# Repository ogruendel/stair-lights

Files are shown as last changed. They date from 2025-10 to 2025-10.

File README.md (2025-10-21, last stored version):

| Supported Targets | ESP32 | ESP32-C2 | ESP32-C3 | ESP32-C5 | ESP32-C6 | ESP32-C61 | ESP32-H2 | ESP32-P4 | ESP32-S2 | ESP32-S3 |
| --- | ----- | --- | --- | --- | --- | --- | --- | --- | --- | --- |

# Blink Example

(See the README.md file in the upper level 'examples' directory for more information about examples.)

This example demonstrates how to blink a LED by using the GPIO driver or using the [led_strip](https://components.espressif.com/component/espressif/led_strip) library if the LED is addressable e.g. [WS2812](https://cdn-shop.adafruit.com/datasheets/WS2812B.pdf). The `led_strip` library is installed via [component manager](main/idf_component.yml).

## How to Use Example

Before project configuration and build, be sure to set the correct chip target using `idf.py set-target <chip_name>`.

### Hardware Required

* A development board with normal LED or addressable LED on-board (e.g., ESP32-S3-DevKitC, ESP32-C6-DevKitC etc.)
* A USB cable for Power supply and programming

See [Development Boards](https://www.espressif.com/en/products/devkits) for more information about it.

### Configure the Project

Open the project configuration menu (`idf.py menuconfig`).

In the `Example Configuration` menu:

* Select the LED type in the `Blink LED type` option.
  * Use `GPIO` for regular LED
  * Use `LED strip` for addressable LED
* If the LED type is `LED strip`, select the backend peripheral
  * `RMT` is only available for ESP targets with RMT peripheral supported
  * `SPI` is available for all ESP targets
* Set the GPIO number used for the signal in the `Blink GPIO number` option.
* Set the blinking period in the `Blink period in ms` option.

### Build and Flash

Run `idf.py -p PORT flash monitor` to build, flash and monitor the project.

(To exit the serial monitor, type ``Ctrl-]``.)

See the [Getting Started Guide](https://docs.espressif.com/projects/esp-idf/en/latest/get-started/index.html) for full steps to configure and use ESP-IDF to build projects.

## Example Output

As you run the example, you will see the LED blinking, according to the previously defined period. For the addressable LED, you can also change the LED color by setting the `led_strip_set_pixel(led_strip, 0, 16, 16, 16);` (LED Strip, Pixel Number, Red, Green, Blue) with values from 0 to 255 in the [source file](main/blink_example_main.c).

```text
I (315) example: Example configured to blink addressable LED!
I (325) example: Turning the LED OFF!
I (1325) example: Turning the LED ON!
I (2325) example: Turning the LED OFF!
I (3325) example: Turning the LED ON!
I (4325) example: Turning the LED OFF!
I (5325) example: Turning the LED ON!
I (6325) example: Turning the LED OFF!
I (7325) example: Turning the LED ON!
I (8325) example: Turning the LED OFF!
```

Note: The color order could be different according to the LED model.

The pixel number indicates the pixel position in the LED strip. For a single LED, use 0.

## Troubleshooting

* If the LED isn't blinking, check the GPIO or the LED type selection in the `Example Configuration` menu.

For any technical queries, please open an [issue](https://github.com/espressif/esp-idf/issues) on GitHub. We will get back to you soon.

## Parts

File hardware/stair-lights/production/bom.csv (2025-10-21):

Designator | Footprint | Quantity | Value | LCSC Part #
 |  | 1
AE1 | 1206 | 1 | Antenna_Chip
BT1 | BatteryHolder_Keystone_1042_1x18650 | 1 | 18650 | C2988620
C1 | 0402 | 1 | 0.5pF
C10, C7 | 0603 | 2 | 1uF | C1592
C11, C12, C13, C18, C5 | 0402 | 5 | 100nF | C6119799
C14, C8, C9 | 0402 | 3 | 4.7uF | C23733
C15, C16 | 0603 | 2 | 10uF | C6119842
C17 | 0603 | 1 | 22uF | C380323
C2, C3 | 0402 | 2 | 12pF | C45359894
C4 | 0402 | 1 | 0.8pF
C6 | 0402 | 1 | 100pF | C77177
D1 | LED_1.7x1.1mm | 1 | LED_RED | C965860
D2 | LED_1.7x1.1mm | 1 | LED_GREEN | C965863
J1 | USB_C_Receptacle_GCT_USB4105-xx-A_16P_TopMnt_Horizontal | 1 | USB_C_Receptacle_USB2.0_14P | C2765186
J2 | JST_XH_S3B-XH-A_1x03_P2.50mm_Horizontal | 1 | Conn_01x03 | C157928
J3 | JST_XH_B3B-XH-AM_1x03_P2.50mm_Vertical | 1 | Conn_01x03 | C161870
J4 | JST_XH_B4B-XH-AM_1x04_P2.50mm_Vertical | 1 | Conn_01x04 | C161871
J5 | JST_XH_S15B-XH-A_1x15_P2.50mm_Horizontal | 1 | Conn_01x15
L1 | 0402 | 1 | 4.7nH
L2 | 1008 | 1 | 0.47uH | C5832368
Q1 | SOT-23 | 1 | SI2301-ZE | C5261052
Q10, Q11, Q12, Q13, Q14, Q15, Q16, Q3, Q4, Q5, Q6, Q7, Q8, Q9 | SOT-23 | 14 | 2302V | C7431443
Q2 | SOT-23-6 | 1 | FS8205A | C2830320
R1, R2 | 0603 | 2 | 5.1k | C26000
R10 | 0402 | 1 | 1M | C26083
R11 | 0603 | 1 | 100R | C2907089
R12 | 0603 | 1 | 2k | C22975
R13, R14, R15, R16, R17, R18, R19, R20, R21, R22, R23, R24, R25, R26, R3, R4, R5 | 0603 | 17 | 220R | C2907127
R6 | 0603 | 1 | 1.2k | C25987
R7 | 0402 | 1 | 511k | C5126239
R8 | 0402 | 1 | 91k | C4147
R9 | 0402 | 1 | 2M | C138014
TP1 | TestPoint_Pad_D1.5mm | 1 | #RST
TP2 | TestPoint_Pad_D1.5mm | 1 | SWDCLK
TP3 | TestPoint_Pad_D1.5mm | 1 | SWDIO
U1 | Nordic_AQFN-73-1EP_7x7mm_P0.5mm | 1 | nRF52840 | C190794
U2 | SOIC-8-1EP_3.9x4.9mm_P1.27mm_EP2.41x3.3mm_ThermalVias | 1 | TP4056-42-ESOP8 | C7473158
U3 | VSON-10 | 1 | TPS63802DLAR | C2845237
U4 | SOT-23-6 | 1 | DW01A | C18164398
Y1 | Crystal_SMD_2016-4Pin_2.0x1.6mm | 1 | Crystal_GND24 | C37635331

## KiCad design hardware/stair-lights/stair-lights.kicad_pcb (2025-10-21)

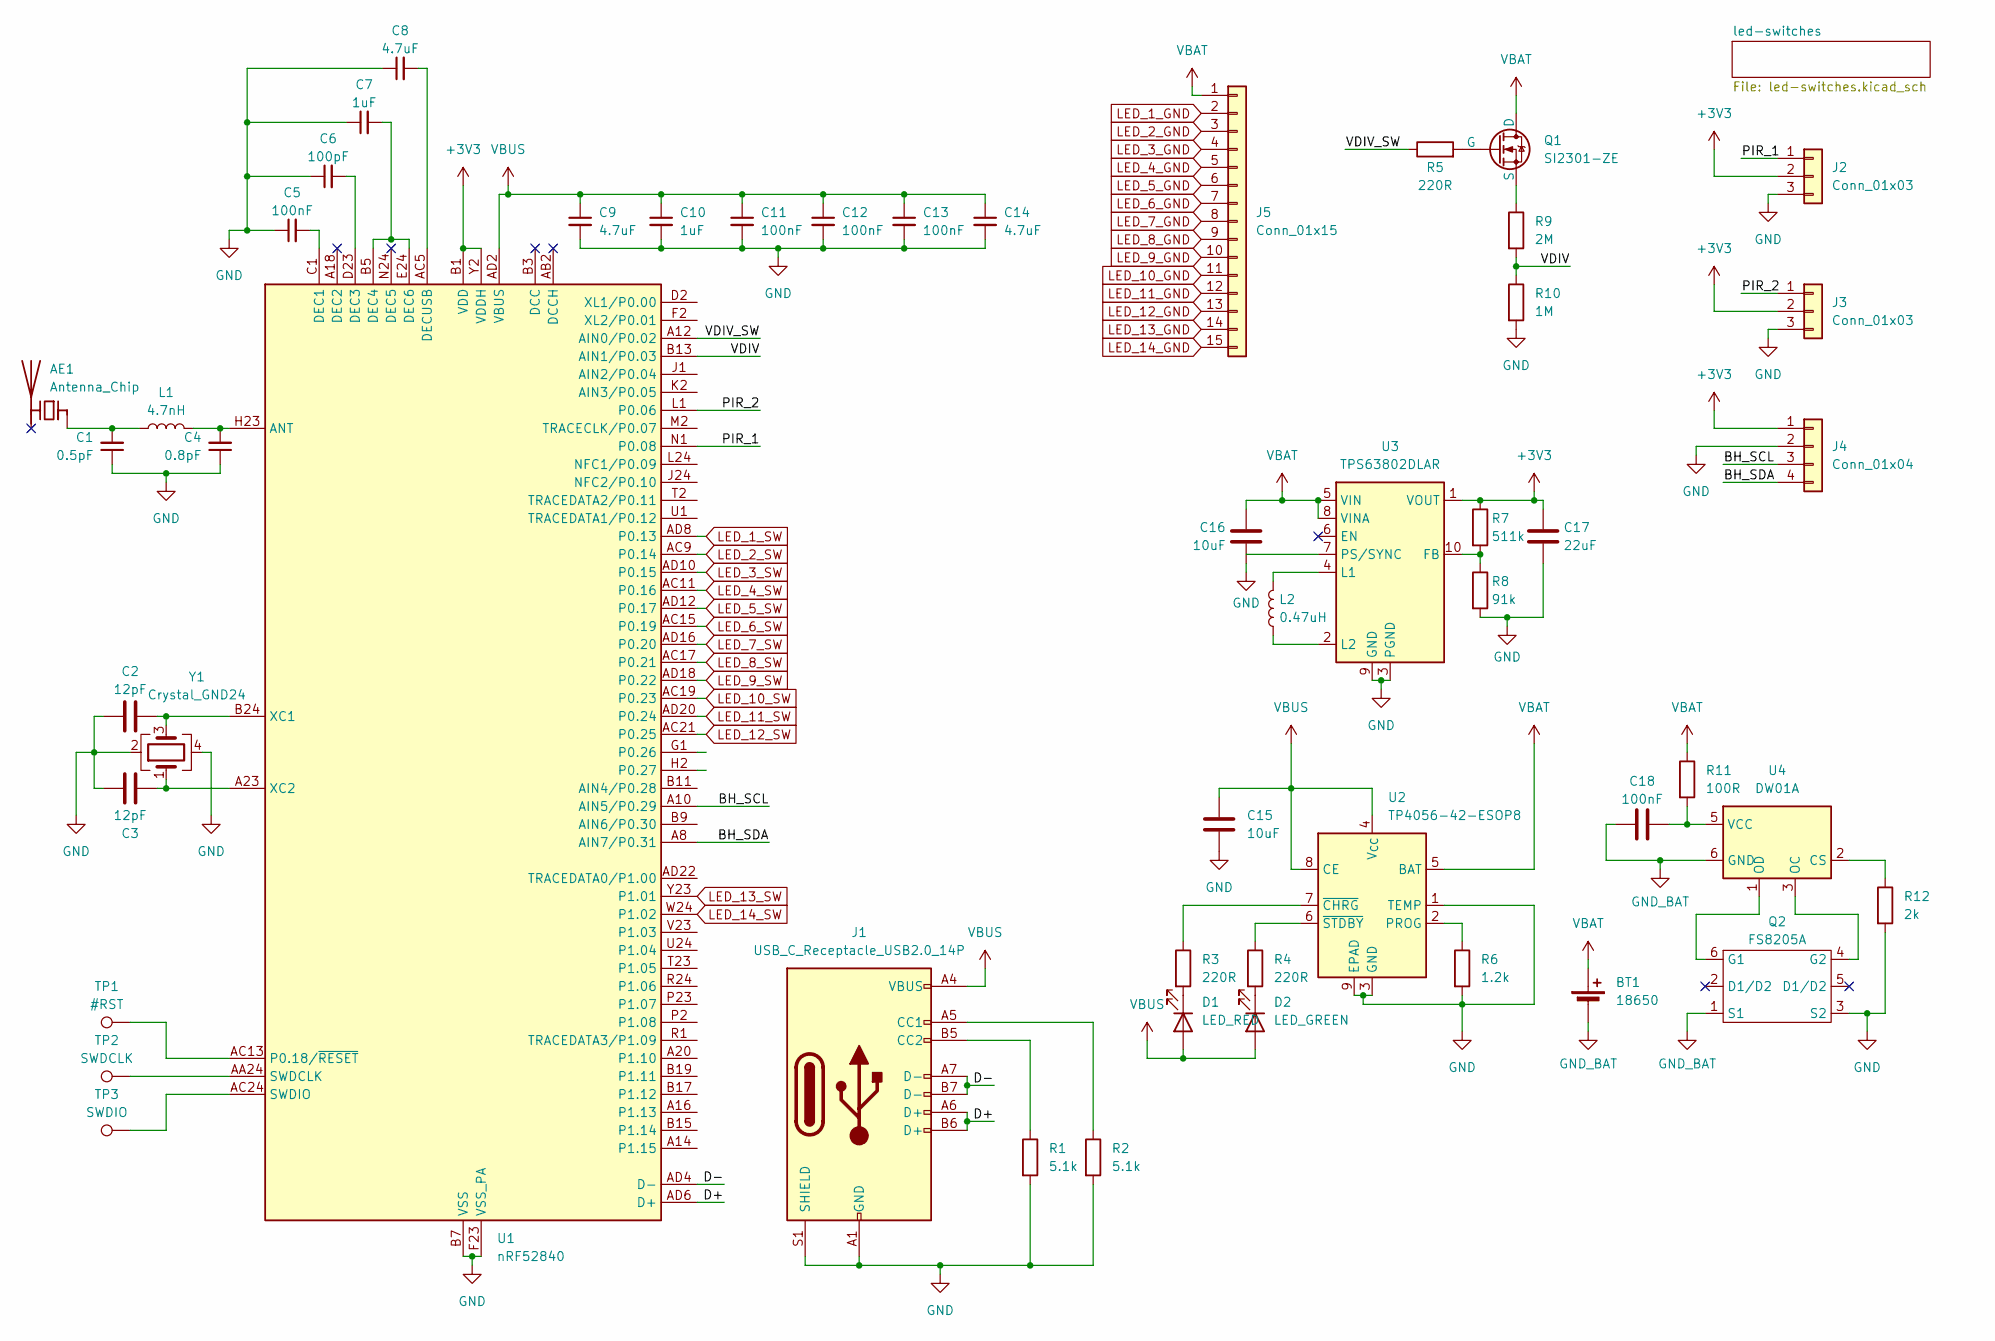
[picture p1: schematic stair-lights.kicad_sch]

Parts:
AE1: Antenna_Chip; L_1206_3216Metric; MPN C127629
BT1: 18650; BatteryHolder_Keystone_1042_1x18650; MPN C2988620
C1: 0.5pF; C_0402_1005Metric; MPN C285052
C2, C3: 12pF; C_0402_1005Metric; MPN C45359894
C4: 0.8pF; C_0402_1005Metric; MPN C41361068
C5, C11, C12, C13, C18: 100nF; C_0402_1005Metric; MPN C6119799
C6: 100pF; C_0402_1005Metric; MPN C77177
C7, C10: 1uF; C_0603_1608Metric; MPN C1592
C8, C9, C14: 4.7uF; C_0402_1005Metric; MPN C23733
C15, C16: 10uF; C_0603_1608Metric; MPN C6119842
C17: 22uF; C_0603_1608Metric; MPN C380323
D1: LED_RED; LED_1.7x1.1mm; MPN C965860
D2: LED_GREEN; LED_1.7x1.1mm; MPN C965863
J1: USB_C_Receptacle_USB2.0_14P; USB_C_Receptacle_GCT_USB4105-xx-A_16P_TopMnt_Horizontal; MPN C2765186
J2: Conn_01x03; JST_XH_S3B-XH-A_1x03_P2.50mm_Horizontal; MPN C157928
J3: Conn_01x03; JST_XH_B3B-XH-AM_1x03_P2.50mm_Vertical; MPN C161870
J4: Conn_01x04; JST_XH_B4B-XH-AM_1x04_P2.50mm_Vertical; MPN C161871
J5: Conn_01x15; JST_XH_S15B-XH-A_1x15_P2.50mm_Horizontal
L1: 4.7nH; L_0402_1005Metric; MPN C86065C86065
L2: 0.47uH; L_1008_2520Metric; MPN C5832368
Q1: SI2301-ZE; SOT-23; MPN C5261052
Q2: FS8205A; SOT-23-6; MPN C2830320
R1, R2: 5.1k; R_0603_1608Metric; MPN C26000
R3, R4, R5: 220R; R_0603_1608Metric; MPN C2907127
R6: 1.2k; R_0603_1608Metric; MPN C25987
R7: 511k; R_0402_1005Metric; MPN C5126239
R8: 91k; R_0402_1005Metric; MPN C4147
R9: 2M; R_0402_1005Metric; MPN C138014
R10: 1M; R_0402_1005Metric; MPN C26083
R11: 100R; R_0603_1608Metric; MPN C2907089
R12: 2k; R_0603_1608Metric; MPN C22975
TP1: #RST; TestPoint_Pad_D1.5mm
TP2: SWDCLK; TestPoint_Pad_D1.5mm
TP3: SWDIO; TestPoint_Pad_D1.5mm
U1: nRF52840; Nordic_AQFN-73-1EP_7x7mm_P0.5mm; MPN C190794
U2: TP4056-42-ESOP8; SOIC-8-1EP_3.9x4.9mm_P1.27mm_EP2.41x3.3mm_ThermalVias; MPN C7473158
U3: TPS63802DLAR; VSON-10; MPN C2845237
U4: DW01A; SOT-23-6; MPN C18164398
Y1: Crystal_GND24; Crystal_SMD_2016-4Pin_2.0x1.6mm; MPN C37635331

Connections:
+3V3: C17.2, J2.2, J3.2, J4.1, R7.1, U1.A22 (VDD), U1.AD14 (VDD), U1.AD23 (VDD), U1.B1 (VDD), U1.W1 (VDD), U1.Y2 (VDDH), U3.1 (VOUT)
/BH_SCL: J4.3, U1.A10 (AIN5/P0.29)
/BH_SDA: J4.4, U1.A8 (AIN7/P0.31)
/D+: J1.A6 (D+), J1.B6 (D+), U1.AD6 (D+)
/D-: J1.A7 (D-), J1.B7 (D-), U1.AD4 (D-)
/PIR_1: J2.1, U1.N1 (P0.08)
/PIR_2: J3.1, U1.L1 (P0.06)
/VDIV: R9.2, R10.1, U1.B13 (AIN1/P0.03)
/VDIV_SW: R5.1, U1.A12 (AIN0/P0.02)
GND: C1.1, C2.1, C3.1, C4.1, C5.1, C6.1, C7.1, C8.1, C9.2, C10.2, C11.2, C12.2, C13.2, C14.2, C15.2, C16.1, C17.1, J1.A1 (GND), J1.A12 (GND), J1.B1 (GND), J1.B12 (GND), J1.S1 (SHIELD), J2.3, J3.3, J4.2, Q2.3 (S2), R1.2, R2.2, R6.2, R8.2, R10.2, R12.2, U1.B7 (VSS), U1.EP (VSS), U1.F23 (VSS_PA), U2.1 (TEMP), U2.3 (GND), U2.9 (EPAD), U3.3 (PGND), U3.9 (GND), Y1.2, Y1.4; also elsewhere on the board
GND_BAT: BT1.2 (-), C18.1, Q2.1 (S1), U4.6 (GND)
LED_1_GND: J5.2; also elsewhere on the board
LED_1_SW: U1.AD8 (P0.13); also elsewhere on the board
LED_2_GND: J5.3; also elsewhere on the board
LED_2_SW: U1.AC9 (P0.14); also elsewhere on the board
LED_3_GND: J5.4; also elsewhere on the board
LED_3_SW: U1.AD10 (P0.15); also elsewhere on the board
LED_4_GND: J5.5; also elsewhere on the board
LED_4_SW: U1.AC11 (P0.16); also elsewhere on the board
LED_5_GND: J5.6; also elsewhere on the board
LED_5_SW: U1.AD12 (P0.17); also elsewhere on the board
LED_6_GND: J5.7; also elsewhere on the board
LED_6_SW: U1.AC15 (P0.19); also elsewhere on the board
LED_7_GND: J5.8; also elsewhere on the board
LED_7_SW: U1.AD16 (P0.20); also elsewhere on the board
LED_8_GND: J5.9; also elsewhere on the board
LED_8_SW: U1.AC17 (P0.21); also elsewhere on the board
LED_9_GND: J5.10; also elsewhere on the board
LED_9_SW: U1.AD18 (P0.22); also elsewhere on the board
LED_10_GND: J5.11; also elsewhere on the board
LED_10_SW: U1.AC19 (P0.23); also elsewhere on the board
LED_11_GND: J5.12; also elsewhere on the board
LED_11_SW: U1.AD20 (P0.24); also elsewhere on the board
LED_12_GND: J5.13; also elsewhere on the board
LED_12_SW: U1.AC21 (P0.25); also elsewhere on the board
LED_13_GND: J5.14; also elsewhere on the board
LED_13_SW: U1.Y23 (P1.01); also elsewhere on the board
LED_14_GND: J5.15; also elsewhere on the board
LED_14_SW: U1.W24 (P1.02); also elsewhere on the board
unnamed: AE1.1 (FEED), C1.2, L1.1
unnamed: D1.1 (K), R3.2
unnamed: D2.1 (K), R4.2
unnamed: J1.A5 (CC1), R2.1
unnamed: J1.B5 (CC2), R1.1
unnamed: Q1.1 (G), R5.2
unnamed: Q1.2 (S), R9.1
unnamed: Q2.6 (G1), U4.1 (OD)
unnamed: Q2.4 (G2), U4.3 (OC)
unnamed: C4.2, L1.2, U1.H23 (ANT)
unnamed: C5.2, U1.C1 (DEC1)
unnamed: C6.2, U1.D23 (DEC3)
unnamed: C7.2, U1.B5 (DEC4), U1.E24 (DEC6)
unnamed: C8.2, U1.AC5 (DECUSB)
unnamed: TP1.1, U1.AC13 (P0.18/~RESET)
unnamed: TP2.1, U1.AA24 (SWDCLK)
unnamed: TP3.1, U1.AC24 (SWDIO)
unnamed: C2.2, U1.B24 (XC1), Y1.3
unnamed: C3.2, U1.A23 (XC2), Y1.1
unnamed: R6.1, U2.2 (PROG)
unnamed: R3.1, U2.7 (~CHRG)
unnamed: R4.1, U2.6 (~STDBY)
unnamed: R7.2, R8.1, U3.10 (FB)
unnamed: L2.2, U3.4 (L1)
unnamed: L2.1, U3.2 (L2)
unnamed: R12.1, U4.2 (CS)
unnamed: C18.2, R11.2, U4.5 (VCC)
VBAT: BT1.1 (+), C16.2, J5.1, Q1.3 (D), R11.1, U2.5 (BAT), U3.5 (VIN), U3.8 (VINA)
VBUS: C9.1, C10.1, C11.1, C12.1, C13.1, C14.1, C15.1, D1.2 (A), D2.2 (A), J1.A4 (VBUS), J1.A9 (VBUS), J1.B4 (VBUS), J1.B9 (VBUS), U1.AD2 (VBUS), U2.4 (V_{CC}), U2.8 (CE)

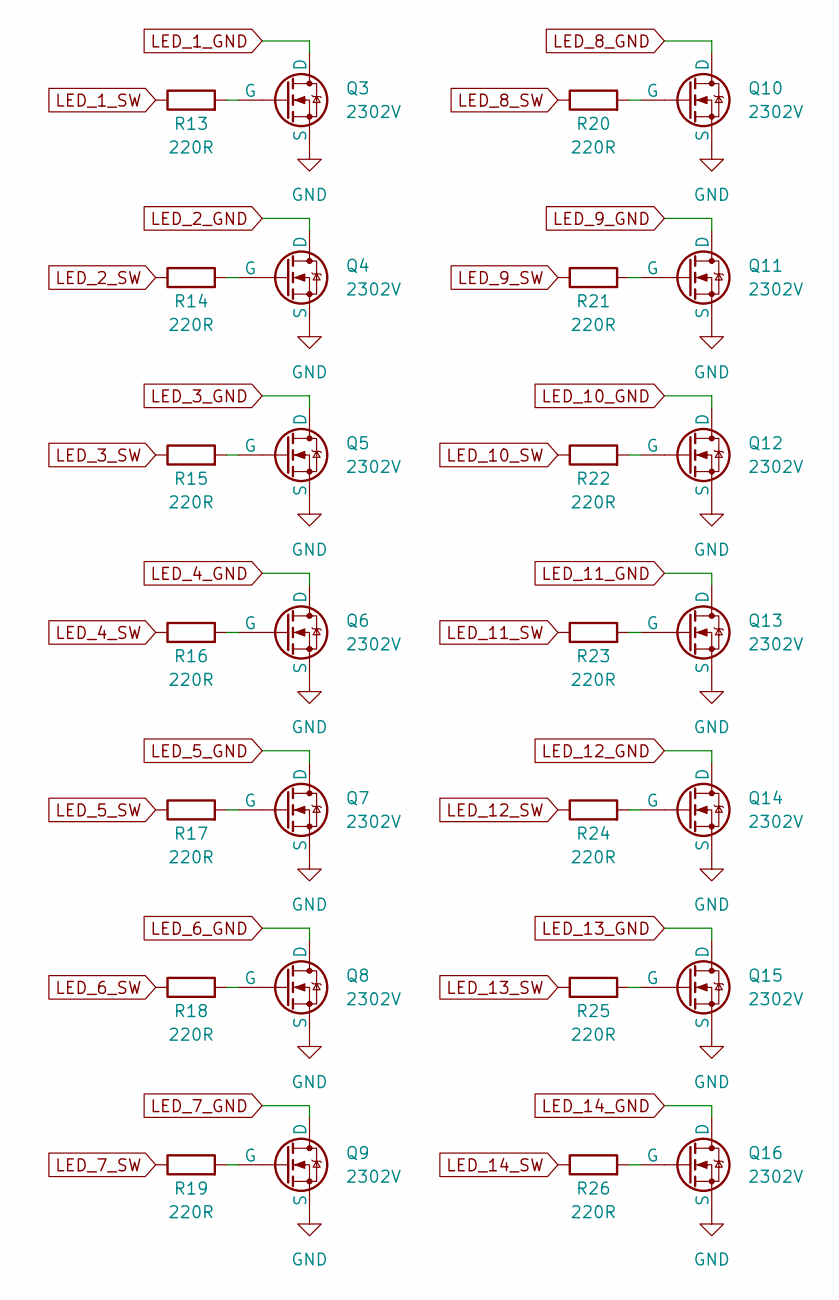
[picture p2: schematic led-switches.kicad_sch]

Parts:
Q3, Q4, Q5, Q6, Q7, Q8, Q9, Q10, Q11, Q12, Q13, Q14, Q15, Q16: 2302V; SOT-23; MPN C7431443
R13, R14, R15, R16, R17, R18, R19, R20, R21, R22, R23, R24, R25, R26: 220R; R_0603_1608Metric; MPN C2907127

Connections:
GND: Q3.2 (S), Q4.2 (S), Q5.2 (S), Q6.2 (S), Q7.2 (S), Q8.2 (S), Q9.2 (S), Q10.2 (S), Q11.2 (S), Q12.2 (S), Q13.2 (S), Q14.2 (S), Q15.2 (S), Q16.2 (S); also elsewhere on the board
LED_1_GND: Q3.3 (D); also elsewhere on the board
LED_1_SW: R13.1; also elsewhere on the board
LED_2_GND: Q4.3 (D); also elsewhere on the board
LED_2_SW: R14.1; also elsewhere on the board
LED_3_GND: Q5.3 (D); also elsewhere on the board
LED_3_SW: R15.1; also elsewhere on the board
LED_4_GND: Q6.3 (D); also elsewhere on the board
LED_4_SW: R16.1; also elsewhere on the board
LED_5_GND: Q7.3 (D); also elsewhere on the board
LED_5_SW: R17.1; also elsewhere on the board
LED_6_GND: Q8.3 (D); also elsewhere on the board
LED_6_SW: R18.1; also elsewhere on the board
LED_7_GND: Q9.3 (D); also elsewhere on the board
LED_7_SW: R19.1; also elsewhere on the board
LED_8_GND: Q10.3 (D); also elsewhere on the board
LED_8_SW: R20.1; also elsewhere on the board
LED_9_GND: Q11.3 (D); also elsewhere on the board
LED_9_SW: R21.1; also elsewhere on the board
LED_10_GND: Q12.3 (D); also elsewhere on the board
LED_10_SW: R22.1; also elsewhere on the board
LED_11_GND: Q13.3 (D); also elsewhere on the board
LED_11_SW: R23.1; also elsewhere on the board
LED_12_GND: Q14.3 (D); also elsewhere on the board
LED_12_SW: R24.1; also elsewhere on the board
LED_13_GND: Q15.3 (D); also elsewhere on the board
LED_13_SW: R25.1; also elsewhere on the board
LED_14_GND: Q16.3 (D); also elsewhere on the board
LED_14_SW: R26.1; also elsewhere on the board
unnamed: Q3.1 (G), R13.2
unnamed: Q4.1 (G), R14.2
unnamed: Q5.1 (G), R15.2
unnamed: Q6.1 (G), R16.2
unnamed: Q7.1 (G), R17.2
unnamed: Q8.1 (G), R18.2
unnamed: Q9.1 (G), R19.2
unnamed: Q10.1 (G), R20.2
unnamed: Q11.1 (G), R21.2
unnamed: Q12.1 (G), R22.2
unnamed: Q13.1 (G), R23.2
unnamed: Q14.1 (G), R24.2
unnamed: Q15.1 (G), R25.2
unnamed: Q16.1 (G), R26.2

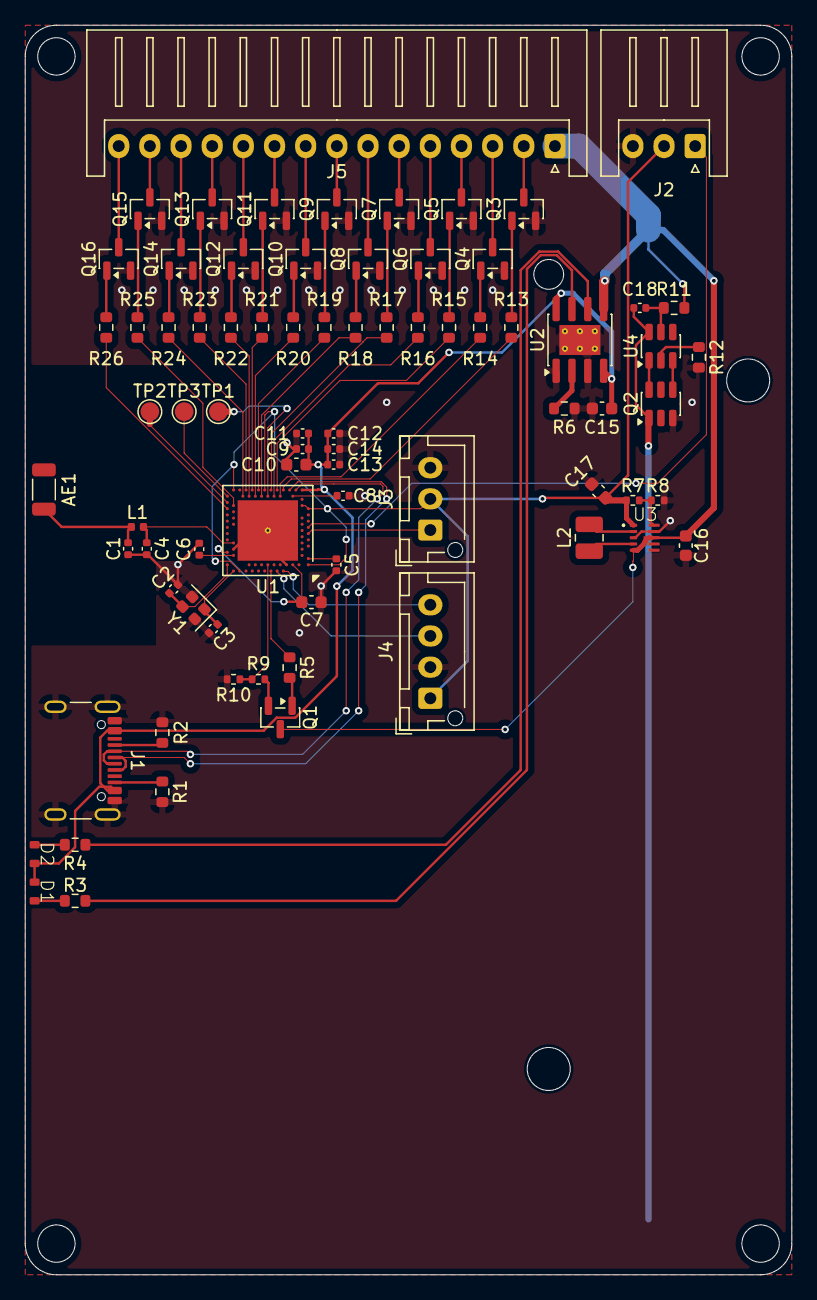
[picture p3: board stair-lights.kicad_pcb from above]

Board: 2 copper layers, 61.5 x 100.2 mm, 79 parts (1 on the bottom side), 82 nets.

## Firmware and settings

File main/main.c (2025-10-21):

#include <stdio.h>
#include "esp_sleep.h"
#include "esp_log.h"
#include "freertos/FreeRTOS.h"
#include "freertos/task.h"
#include "driver/rtc_io.h"
#include "main.h"


void app_main(void) {
    gpio_config(&pir_conf);

    adc_oneshot_unit_handle_t adc1_handle;
    adc_oneshot_unit_init_cfg_t init_config1 = {
        .unit_id = ADC_UNIT_1,
    };

    adc_oneshot_new_unit(&init_config1, &adc1_handle);

    adc_oneshot_chan_cfg_t channel_config = {
        .atten = ADC_ATTEN_DB_12,
        .bitwidth = ADC_BITWIDTH_DEFAULT
    };

    adc_oneshot_config_channel(adc1_handle, VBAT, &channel_config);

    ledc_timer_config(&high_timer_config_1);
    ledc_timer_config(&high_timer_config_2);
    ledc_timer_config(&high_timer_config_3);
    ledc_timer_config(&high_timer_config_4);
    ledc_timer_config(&low_timer_config_1);
    ledc_timer_config(&low_timer_config_2);
    ledc_timer_config(&low_timer_config_3);

    ledc_channel_config(&led_1_pwm);
    ledc_channel_config(&led_2_pwm);
    ledc_channel_config(&led_3_pwm);
    ledc_channel_config(&led_4_pwm);
    ledc_channel_config(&led_5_pwm);
    ledc_channel_config(&led_6_pwm);
    ledc_channel_config(&led_7_pwm);
    ledc_channel_config(&led_8_pwm);
    ledc_channel_config(&led_9_pwm);
    /*
    ledc_channel_config(&led_10_pwm);
    ledc_channel_config(&led_11_pwm);
    ledc_channel_config(&led_12_pwm);
    ledc_channel_config(&led_13_pwm);
    ledc_channel_config(&led_14_pwm);
    */
    ledc_channel_config_t led_confs[9] = {led_1_pwm, led_2_pwm, led_3_pwm, led_4_pwm, led_5_pwm, led_6_pwm, led_7_pwm, led_8_pwm, led_9_pwm};

    esp_sleep_enable_ext1_wakeup_io((1ULL << PIR_1) | (1ULL << PIR_2), ESP_EXT1_WAKEUP_ANY_HIGH);

    TaskHandle_t xHandle = NULL;

    ESP_LOGI("Main", "Setting up Task");
    ESP_LOGI("Main", "%d", esp_sleep_get_wakeup_cause());

    static int adc_value[2][10];
    adc_oneshot_read(adc1_handle, VBAT, &adc_value[0][0]);

    ESP_LOGI("Main", "Vbat: %f", (adc_value[0][0] * 3300) / 4095 * 1.285);

    uint8_t pir_bottom = gpio_get_level(PIR_1);
    uint8_t pir_top = gpio_get_level(PIR_2);

    if (pir_bottom == 1) {
        ESP_LOGI(TAG, "PIR Bottom");
        for (int i = 0; i < 9; i++) {
            gpio_hold_dis(led_confs[i].gpio_num);
            xTaskCreate(fade_on, "Fade On", 1024, (void*)&led_confs[i], 10, &xHandle);
            vTaskDelay(pdMS_TO_TICKS(100));
        }

        vTaskDelay(pdMS_TO_TICKS(LIGHT_ON * 1000));
    } else if (pir_top == 1) {
        ESP_LOGI(TAG, "PIR Top");
        for (int i = 8; i >= 0; i--) {
            gpio_hold_dis(led_confs[i].gpio_num);
            xTaskCreate(fade_on, "Fade On", 1024, (void*)&led_confs[i], 10, &xHandle);
            vTaskDelay(pdMS_TO_TICKS(100));
        }

        vTaskDelay(pdMS_TO_TICKS(LIGHT_ON * 1000));
    }

    for (int i = 8; i >= 0; i--) {
        xTaskCreate(fade_off, "Fade off", 1024, (void*)&led_confs[i], 10, &xHandle);
    }

    vTaskDelay(pdMS_TO_TICKS(1000));
    esp_deep_sleep_start();
}

void fade_on(void *pvParam) {
    ledc_channel_config_t *pwm_conf = pvParam;
    ledc_mode_t speed_mode = pwm_conf->speed_mode;
    ledc_channel_t channel = pwm_conf->channel;

    for (int i = 0; i < BRIGHTNESS; i++) {
        ledc_set_duty(speed_mode, channel, (uint32_t)(255 * (i / 100.0)));
        ledc_update_duty(speed_mode, channel);
        vTaskDelay(pdMS_TO_TICKS(BRIGHTNESS_DELAY));
    }
    vTaskDelete(NULL);
}

void fade_off(void* pvParam) {
    ledc_channel_config_t *pwm_conf = pvParam;
    ledc_mode_t speed_mode = pwm_conf->speed_mode;
    ledc_channel_t channel = pwm_conf->channel;

    for (int i = BRIGHTNESS; i >= 0; i--) {
        ledc_set_duty(speed_mode, channel, (uint32_t)(255 * (i / 100.0)));
        ledc_update_duty(speed_mode, channel);
        vTaskDelay(pdMS_TO_TICKS(BRIGHTNESS_DELAY));
    }
    gpio_hold_en(pwm_conf->gpio_num);
    vTaskDelete(NULL);
}

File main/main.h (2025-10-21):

#include <stdio.h>
#include "driver/gpio.h"
#include "driver/ledc.h"
#include "esp_adc/adc_oneshot.h"
#include "esp_adc/adc_cali.h"
#include "esp_adc/adc_cali_scheme.h"

// PIR Top: IO34
// PIR Bottom: IO2
// VBAT: IO35
// SCL: IO22
// SDA: IO21
// LED_1: IO32
// LED_2: IO33
// LED_3: IO25
// LED_4: IO14
// LED_5: IO27
// LED_6: IO26
// LED_7: IO13
// LED_8: IO23
// LED_9: IO19
// LED_10: IO18
// LED_11: IO5
// LED_12: IO17
// LED_13: IO16
// LED_14: IO4

#define TAG "Main"

#define BRIGHTNESS 10
#define BRIGHTNESS_DELAY 25 
#define PIR_1 GPIO_NUM_2
#define PIR_2 GPIO_NUM_34
#define VBAT ADC_CHANNEL_7

#define LIGHT_ON 60

const int LEDS[9] = {GPIO_NUM_32, GPIO_NUM_33, GPIO_NUM_25, GPIO_NUM_18, GPIO_NUM_27, GPIO_NUM_26, GPIO_NUM_13, GPIO_NUM_23, GPIO_NUM_19};

gpio_config_t pir_conf = {
    .pin_bit_mask = (1ULL << PIR_1) | (1ULL << PIR_2),
    .mode = GPIO_MODE_INPUT,
    .pull_up_en = GPIO_PULLUP_DISABLE,
    .pull_down_en = GPIO_PULLDOWN_DISABLE,
    .intr_type = GPIO_INTR_DISABLE
};
ledc_timer_config_t high_timer_config_1 = {
    .speed_mode = LEDC_HIGH_SPEED_MODE,
    .duty_resolution = LEDC_TIMER_8_BIT,
    .timer_num = LEDC_TIMER_0,
    .freq_hz = 1000
};

ledc_timer_config_t high_timer_config_2 = {
    .speed_mode = LEDC_HIGH_SPEED_MODE,
    .duty_resolution = LEDC_TIMER_8_BIT,
    .timer_num = LEDC_TIMER_1,
    .freq_hz = 1000
};

ledc_timer_config_t high_timer_config_3 = {
    .speed_mode = LEDC_HIGH_SPEED_MODE,
    .duty_resolution = LEDC_TIMER_8_BIT,
    .timer_num = LEDC_TIMER_2,
    .freq_hz = 1000
};

ledc_timer_config_t high_timer_config_4 = {
    .speed_mode = LEDC_HIGH_SPEED_MODE,
    .duty_resolution = LEDC_TIMER_8_BIT,
    .timer_num = LEDC_TIMER_3,
    .freq_hz = 1000
};

ledc_timer_config_t low_timer_config_1 = {
    .speed_mode = LEDC_LOW_SPEED_MODE,
    .duty_resolution = LEDC_TIMER_8_BIT,
    .timer_num = LEDC_TIMER_0,
    .freq_hz = 1000
};

ledc_timer_config_t low_timer_config_2 = {
    .speed_mode = LEDC_LOW_SPEED_MODE,
    .duty_resolution = LEDC_TIMER_8_BIT,
    .timer_num = LEDC_TIMER_1,
    .freq_hz = 1000
};

ledc_timer_config_t low_timer_config_3 = {
    .speed_mode = LEDC_LOW_SPEED_MODE,
    .duty_resolution = LEDC_TIMER_8_BIT,
    .timer_num = LEDC_TIMER_2,
    .freq_hz = 1000
};


ledc_channel_config_t led_1_pwm = {
    .gpio_num = LEDS[0],
    .speed_mode = LEDC_HIGH_SPEED_MODE,
    .channel = LEDC_CHANNEL_0,
    .duty = 0,
};

ledc_channel_config_t led_2_pwm = {
    .gpio_num = LEDS[1],
    .speed_mode = LEDC_HIGH_SPEED_MODE,
    .channel = LEDC_CHANNEL_1,
    .duty = 0,
};

ledc_channel_config_t led_3_pwm = {
    .gpio_num = LEDS[2],
    .speed_mode = LEDC_HIGH_SPEED_MODE,
    .channel = LEDC_CHANNEL_2,
    .duty = 0,
};

ledc_channel_config_t led_4_pwm = {
    .gpio_num = LEDS[3],
    .speed_mode = LEDC_HIGH_SPEED_MODE,
    .channel = LEDC_CHANNEL_3,
    .duty = 0,
};

ledc_channel_config_t led_5_pwm = {
    .gpio_num = LEDS[4],
    .speed_mode = LEDC_HIGH_SPEED_MODE,
    .channel = LEDC_CHANNEL_4,
    .duty = 0,
};

ledc_channel_config_t led_6_pwm = {
    .gpio_num = LEDS[5],
    .speed_mode = LEDC_HIGH_SPEED_MODE,
    .channel = LEDC_CHANNEL_5,
    .duty = 0,
};

ledc_channel_config_t led_7_pwm = {
    .gpio_num = LEDS[6],
    .speed_mode = LEDC_HIGH_SPEED_MODE,
    .channel = LEDC_CHANNEL_6,
    .duty = 0,
};

ledc_channel_config_t led_8_pwm = {
    .gpio_num = LEDS[7],
    .speed_mode = LEDC_HIGH_SPEED_MODE,
    .channel = LEDC_CHANNEL_7,
    .duty = 0,
};

ledc_channel_config_t led_9_pwm = {
    .gpio_num = LEDS[8],
    .speed_mode = LEDC_LOW_SPEED_MODE,
    .channel = LEDC_CHANNEL_0,
    .duty = 0,
};

/*
ledc_channel_config_t led_10_pwm = {
    .gpio_num = LEDS[9],
    .speed_mode = LEDC_LOW_SPEED_MODE,
    .channel = LEDC_CHANNEL_1,
    .duty = 0,
};

ledc_channel_config_t led_11_pwm = {
    .gpio_num = LEDS[10],
    .speed_mode = LEDC_LOW_SPEED_MODE,
    .channel = LEDC_CHANNEL_2,
    .duty = 0,
};

ledc_channel_config_t led_12_pwm = {
    .gpio_num = LEDS[11],
    .speed_mode = LEDC_LOW_SPEED_MODE,
    .channel = LEDC_CHANNEL_3,
    .duty = 0,
};

ledc_channel_config_t led_13_pwm = {
    .gpio_num = LEDS[12],
    .speed_mode = LEDC_LOW_SPEED_MODE,
    .channel = LEDC_CHANNEL_4,
    .duty = 0,
};

ledc_channel_config_t led_14_pwm = {
    .gpio_num = LEDS[13],
    .speed_mode = LEDC_LOW_SPEED_MODE,
    .channel = LEDC_CHANNEL_5,
    .duty = 0,
};
*/

void fade_on(void *pvParam);
void fade_off(void* pvParam);
